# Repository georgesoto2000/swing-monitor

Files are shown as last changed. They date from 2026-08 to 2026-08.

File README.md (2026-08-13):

# Swing Monitor

Arduino sensor project for golf. Mounted IMU sensor on the club shaft allows for live measuring (and transfer of data over IoT/BLE in real time for display) of per-swing metrics, all derived from the shaft-mounted IMU's accelerometer, gyroscope, and fused orientation output.

## Key Metrics

**Speed**
* Peak clubhead speed
* Clubhead speed at impact

**Timing**
* Backswing time (address → top)
* Downswing time (top → impact)
* Tempo ratio (backswing:downswing)
* Total swing time

**Plane**
* Swing plane angle
* Plane angle delta (top of backswing vs. impact)

**Rotational / release**
* Peak angular velocity (wrist/face rotation rate)
* Timing of peak angular velocity relative to impact (early = casting, late = lag/release)

**Impact**
* Peak acceleration spike at impact (magnitude and sharpness)
* Angle of attack at impact (steep vs. shallow) — noisier, since it depends on precise impact detection from the accelerometer alone

## Hardware

* [Ardunio Nano ESP32](https://thepihut.com/products/arduino-nano-esp32-with-headers)
* [Adafruit 9-DOF Orentiation IMU Fusion Breakout - BNO085](https://thepihut.com/products/adafruit-9-dof-orientation-imu-fusion-breakout-bno085-bno080-stemma-qt-qwiic)
* LiPo 3.7v Battery
* 3D printed casing

## Project Plan

1. **Hardware assembly** — wire BNO085 to Nano ESP32 (I2C/Qwiic), confirm power draw against LiPo capacity, mount in 3D printed casing on shaft
2. **Sensor bring-up** — read raw accelerometer/gyroscope and fused orientation (quaternion) output from the BNO085, verify sample rate is sufficient to capture a swing (target 100Hz+) — see [`firmware/sensor_bringup`](firmware/sensor_bringup/sensor_bringup.ino)
3. **Swing event detection** — segment a continuous data stream into address, top of backswing, impact, and finish
4. **Metric calculation** — compute per-swing metrics (speed, timing, plane, rotational/release, impact) from segmented data
5. **Calibration & validation** — sanity-check computed metrics against known reference values (e.g. compare clubhead speed estimates to a radar/launch monitor) and tune impact/event detection thresholds
6. **Data transfer** — stream metrics over BLE from the Nano ESP32
7. **Display** — companion app or device to receive and display metrics in real time
8. **Enclosure refinement** — iterate on 3D printed casing for secure, low-profile shaft mounting

## Python Coding Standards

* All functions and classes should be docstring-ed and type hinted

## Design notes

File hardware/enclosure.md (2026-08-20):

# 3D Print Enclosure

## Requirements

* Enclosure must clip onto the shaft
* Enclosure must contain the PCB and battery
* Enclosure must snap onto the shaft
* USBC is not required to be accessible
* LED is not required to be visible
* PLA filament
* Mounted near grip of golf club
* The Y axis of the PCB should point up the shaft

## Dimensions

* Shaft mounting location diameter: 13mm
* Shaft diameter at the bottom: 9mm
* PCB (and battery): X 45mm, Y 70mm, Z 30mm
* On/off switch hole: 6mm, +X side wall, centered along the case
  length, 5mm below the lid lip's bottom edge

## Open Questions

* Battery retention not decided - fix down (foam tape / printed strap,
  not screws - puncture risk) vs. leave free in the cavity. Currently
  unaddressed in enclosure.scad.

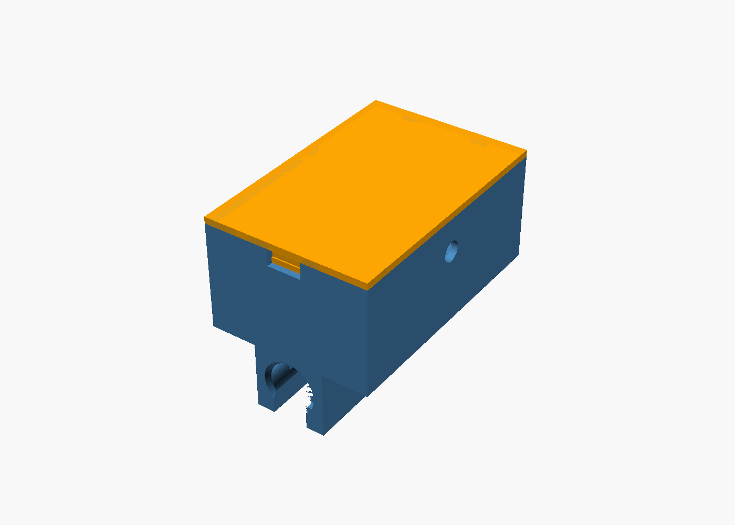
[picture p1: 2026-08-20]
hardware/enclosure_preview.png

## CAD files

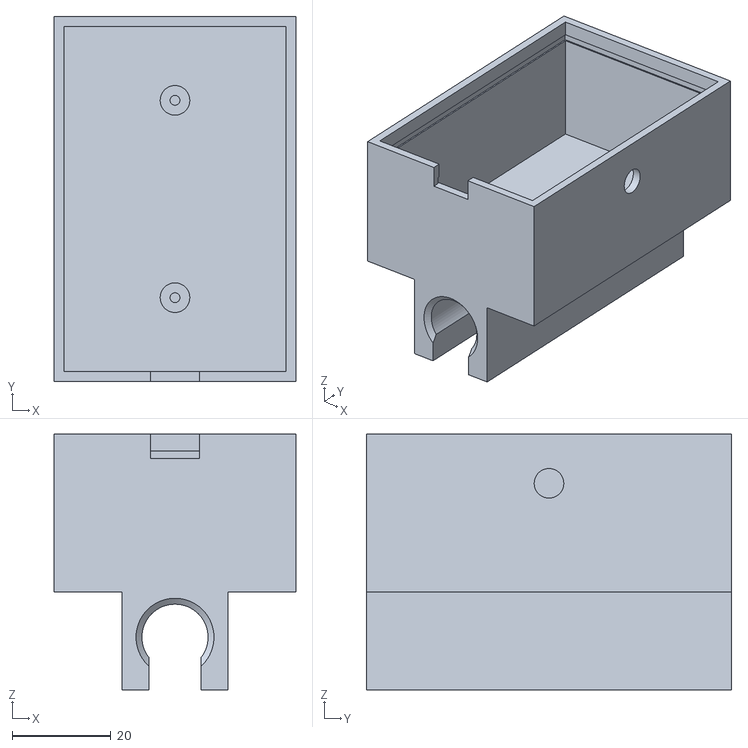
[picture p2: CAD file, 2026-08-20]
hardware/enclosure_base.stl
49.0 x 74.0 x 51.9

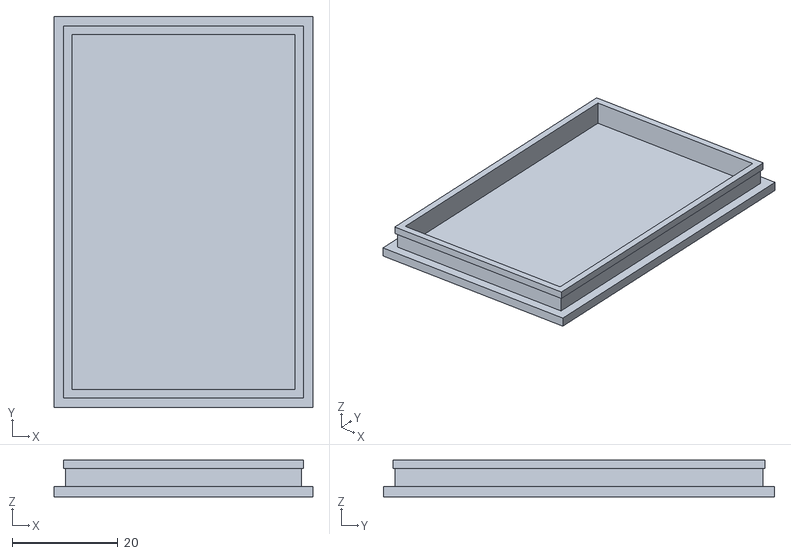
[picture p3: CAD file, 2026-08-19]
hardware/enclosure_lid.stl
49.0 x 74.0 x 7.00

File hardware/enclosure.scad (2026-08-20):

// Swing Monitor - shaft-mount enclosure
// Parametric OpenSCAD model driven by hardware/encloser.md
//
// Design (see chat / README for full rationale):
//  - Two-piece shell: "base" (5 closed sides, open top) + flat "lid"
//    that snaps into the open top via a thin flexible lip with a
//    perimeter bead, which pops into a matching groove in the cavity
//    wall - same thin-wall-interference idea as the shaft clip below,
//    just applied as a rectangular loop instead of a circular one.
//  - A pry notch is cut into one end of the base's rim so there's
//    somewhere to get a fingernail/thin tool under the lid to release
//    the bead and lift it off (it clicks shut positively, so a flush
//    friction-only seam would be very hard to open).
//  - A solid rectangular ring is fused to the underside of the base,
//    bored through with a circular hole for the shaft plus a straight
//    capture slot connecting the bore to the outside (gap facing
//    down). It's installed by clipping it sideways onto the shaft at
//    a point where the shaft is already narrower than the slot (no
//    flexing needed to get it on), then sliding it up the taper until
//    the bore wedges tight at the 13mm mounting point. Because the
//    slot width sits between "narrow enough to clip on" and "too
//    narrow to slip back off at 13mm", it self-retains without ever
//    needing to flex - so the ring can be fully rigid.
//    (v1 used a thin C-clip that snapped on radially by flexing open
//    over the full 13mm - it cracked in testing: PLA has very low
//    elongation at break, and the clip also put a sharp stress-riser
//    right at the weakest print-adhesion seam. v2 tried a fully closed
//    sliding sleeve, but that can't get past a fixed/epoxied clubhead.
//    This version avoids both problems - no flex, and installs without
//    removing the head.)
//  - slot_w = 10.5mm: measured shaft diameter at the clip-on point is
//    ~9mm, so this gives ~1.5mm clearance to clip on without force
//    (also covers FDM holes typically printing a touch undersized),
//    while staying 2.5mm under shaft_d (13mm) so the ring can't slip
//    sideways back off once slid up to the mount point. If the fit
//    feels wrong either way after printing, it's a one-line tweak.
//  - Case Y axis runs parallel to the shaft (per encloser.md: "Y axis
//    of the PCB should point up the shaft").
//
// Assumptions made beyond encloser.md (flagged in chat - revisit after
// a test fit):
//  - encloser.md's PCB+battery box (45 x 70 x 30) is treated as the
//    required INTERNAL cavity, not an outer envelope.
//  - 2mm shell walls, 1.2mm lid-lip walls (thin enough to flex for a
//    PLA snap-fit - the lid still relies on flexing, unlike the sleeve).
//  - Sleeve bore is sized shaft_d + slide_clearance for an easy slide
//    fit; nothing here guarantees it stops/grips exactly at the 13mm
//    point without knowing the real taper profile, so plan on a wrap
//    of grip tape over the sleeve's top edge (traps it from sliding
//    further up) and/or a dab of glue for final retention.
//  - PCB (veroboard, screwed through a flange) sits on two 5mm-tall
//    bosses with blind M2.5 self-tap pilot holes rather than one
//    continuous ledge - same holding strength for a 2-point mount,
//    less material/print time. boss_pos below is a PLACEHOLDER
//    (centered in X, guessed spacing in Y) - it has not been checked
//    against your actual flange hole positions, update it to match
//    before printing for real.
//  - Bead/groove sizes on the lid are a first-pass guess at PLA's
//    flex - print and test; loosen (reduce bead_h) if it's too tight
//    to open, tighten if it doesn't hold.

$fn = 64;

// ---- tunable parameters ----
shaft_d      = 13;    // shaft diameter at the mount point (mm)
box_x        = 45;    // internal cavity width  (X)
box_y        = 70;    // internal cavity length (Y) - parallel to shaft
box_z        = 30;    // internal cavity height (Z)
wall         = 2;     // shell wall thickness (mm)
slide_clear  = 0.4;   // sleeve bore clearance over shaft_d, for sliding on (mm)
sleeve_wall  = 4;     // sleeve wall thickness - rigid, no flex needed (mm)
sleeve_chamfer = 1.2; // lead-in chamfer at the sleeve's ends (mm)
sleeve_overlap = 1.5; // how far the sleeve's top face sits inside the
                       // base's bottom slab (0..wall), for a solid weld
slot_w       = 10.5;  // capture-slot width (mm) - see note above:
                       // shaft-diameter-at-clip-on-point < slot_w < shaft_d
lip_h        = 5;     // lid lip depth (mm)
lip_wall     = 1.2;   // lid lip wall thickness (thin, so it can flex)
lid_clear    = 0.2;   // nominal lid-to-cavity fit clearance per side (mm)
bead_h       = 0.4;   // snap-bead radial projection beyond the lip (mm)
bead_band    = 1.6;   // height of the bead / matching groove band (mm)
groove_clear = 0.15;  // extra clearance in the groove vs the bead (mm)
notch_w      = 10;    // pry-notch width, cut into the rim at y=0 (mm)
notch_d      = 5;     // pry-notch depth, down from the rim (mm)
boss_h       = 5;     // PCB standoff boss height, off the cavity floor (mm)
boss_od      = 6;     // boss outer diameter (mm)
pilot_d      = 2.0;   // pilot hole diameter for a self-tapping M2.5 (mm)
pilot_depth  = 4.5;   // blind pilot hole depth from the boss top (mm)
// PLACEHOLDER positions (x, y) in cavity-local coords: x=0 is the
// cavity centreline, y=0..box_y runs the cavity's length - MUST be
// updated to match your veroboard flange's real hole spacing
boss_pos     = [[0, 15], [0, 55]];

// on/off switch hole - straight through-hole in the +X long wall,
// for a panel-mount toggle/rocker switch (6mm is a common bushing
// size for these - check it matches whatever switch you buy, and
// that its bushing is rated for a ~2mm panel, i.e. the wall thickness)
hole_d       = 6;     // hole diameter (mm)
hole_below_lip = 5;   // "5mm lower than the ledge for the lid" - measured
                       // from the BOTTOM of the lid's lip (z = box_z+wall-lip_h),
                       // not the rim itself, since the rim sits right in the
                       // snap-groove band and a hole there would weaken it

// ---- derived ----
out_x      = box_x + 2*wall;
out_y      = box_y + 2*wall;
sleeve_id  = shaft_d + slide_clear;
sleeve_od  = sleeve_id + 2*sleeve_wall;
lip_ox     = box_x - 2*lid_clear;               // lip outer footprint
lip_oy     = box_y - 2*lid_clear;
lip_ix     = lip_ox - 2*lip_wall;                // lip inner (hollow) footprint
lip_iy     = lip_oy - 2*lip_wall;
groove_x   = lip_ox + 2*bead_h + 2*groove_clear; // groove cut footprint
groove_y   = lip_oy + 2*bead_h + 2*groove_clear;

module shaft_sleeve() {
    // rigid block: circular bore for the shaft, plus a straight
    // capture slot (constant width slot_w) connecting the bore to the
    // outside at the bottom, so the shaft clips in sideways rather
    // than needing to be threaded through an end
    z_center = sleeve_overlap - sleeve_od/2;
    translate([0, 0, z_center]) {
        difference() {
            translate([-sleeve_od/2, 0, -sleeve_od/2])
                cube([sleeve_od, out_y, sleeve_od]);
            rotate([-90, 0, 0])
                cylinder(d = sleeve_id, h = out_y + 2, center = false);
            // lead-in chamfers at both ends so it doesn't catch/scrape
            // as it's slid up the shaft's taper, either way round
            rotate([-90, 0, 0])
                cylinder(d1 = sleeve_id + 2*sleeve_chamfer, d2 = sleeve_id,
                         h = sleeve_chamfer);
            translate([0, out_y - sleeve_chamfer, 0])
                rotate([-90, 0, 0])
                    cylinder(d1 = sleeve_id, d2 = sleeve_id + 2*sleeve_chamfer,
                             h = sleeve_chamfer);
            // capture slot - straight channel from the bore's centre
            // (local z=0) down through the block's bottom face
            translate([-slot_w/2, -1, -sleeve_od/2 - 1])
                cube([slot_w, out_y + 2, sleeve_od/2 + 1]);
        }
    }
}

module groove_2d() {
    difference() {
        square([groove_x, groove_y], center = true);
        square([box_x, box_y], center = true);
    }
}

module pry_notch() {
    // through the y=0 end wall, from the rim down by notch_d
    translate([-notch_w/2, -1, box_z + wall - notch_d])
        cube([notch_w, wall + 2, notch_d + 1]);
}

module side_hole() {
    // on/off switch, panel-mounted through the +X long wall, centered
    // along the case length
    hole_z = (box_z + wall - lip_h) - hole_below_lip;
    translate([out_x/2 - wall - 2, wall + box_y/2, hole_z])
        rotate([0, 90, 0])
            cylinder(d = hole_d, h = wall + 4);
}
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

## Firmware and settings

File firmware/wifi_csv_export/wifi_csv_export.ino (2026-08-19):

// Swing Monitor — Wireless CSV Export (WiFi)
//
// The board hosts its own WiFi hotspot (no router or existing network
// needed — works anywhere, e.g. a driving range) and streams accelerometer,
// gyroscope, and rotation vector (quaternion) readings as CSV rows over TCP
// to whichever laptop joins that hotspot.
//
// Setup:
// 1. Upload and power the board (USB or battery). It'll print its hotspot
//    SSID and IP address (normally 192.168.4.1) to Serial.
// 2. On your laptop, join the WiFi network below (you'll lose general
//    internet access while connected — expected, the board isn't routing
//    to the internet).
// 3. Start capturing to a file:
//        nc 192.168.4.1 5005 > swing_data.csv
// 4. When done, Ctrl+C the `nc` command to close the file.
//
// CSV columns: millis,type,x,y,z,w  (w only populated for QUAT rows)

#include <Wire.h>
#include <WiFi.h>
#include <Adafruit_BNO08x.h>

const char* AP_SSID = "swing-monitor";
const char* AP_PASSWORD = "swingmonitor123";  // WPA2 requires 8+ characters
const uint16_t SERVER_PORT = 5005;

#define BNO08X_RESET -1

Adafruit_BNO08x bno08x(BNO08X_RESET);
sh2_SensorValue_t sensorValue;
WiFiServer server(SERVER_PORT);
WiFiClient client;

// 200Hz — comfortably above the 100Hz+ target.
const uint32_t REPORT_INTERVAL_US = 5000;

void setReports() {
  bno08x.enableReport(SH2_ACCELEROMETER, REPORT_INTERVAL_US);
  bno08x.enableReport(SH2_GYROSCOPE_CALIBRATED, REPORT_INTERVAL_US);
  bno08x.enableReport(SH2_ROTATION_VECTOR, REPORT_INTERVAL_US);
}

void startAccessPoint() {
  WiFi.softAP(AP_SSID, AP_PASSWORD);
  Serial.print("Hotspot \"");
  Serial.print(AP_SSID);
  Serial.print("\" up, IP: ");
  Serial.println(WiFi.softAPIP());
  server.begin();
}

void setup() {
  Serial.begin(115200);

  startAccessPoint();

  if (!bno08x.begin_I2C()) {
    Serial.println("Failed to find BNO085 - check wiring");
    while (1) {
      delay(10);
    }
  }

  // Bump from the 100kHz default to 400kHz (I2C fast mode) — set after
  // begin_I2C() so the library's own Wire.begin() doesn't reset it back.
  Wire.setClock(400000);

  setReports();

  Serial.println("Waiting for laptop to connect...");
}

void sendRow(uint32_t t, const char* type, float x, float y, float z, float w, bool hasW) {
  // Build the whole row and send it as a single write — sending each field
  // as a separate client.print() call was six TCP writes per sample, which
  // over WiFi was slow enough to throttle the achievable sample rate well
  // below the sensor's actual output rate.
  char buf[96];
  int len;
  if (hasW) {
    len = snprintf(buf, sizeof(buf), "%lu,%s,%.4f,%.4f,%.4f,%.4f\n", t, type, x, y, z, w);
  } else {
    len = snprintf(buf, sizeof(buf), "%lu,%s,%.4f,%.4f,%.4f,\n", t, type, x, y, z);
  }
  client.write((const uint8_t*)buf, len);
}

void loop() {
  if (bno08x.wasReset()) {
    setReports();
  }

  if (!client.connected()) {
    client = server.available();
    if (client) {
      client.setNoDelay(true);  // don't let TCP delay small writes waiting to batch
      Serial.println("Laptop connected - streaming CSV");
      client.println("millis,type,x,y,z,w");
    }
    return;
  }

  if (!bno08x.getSensorEvent(&sensorValue)) {
    return;
  }

  uint32_t t = millis();

  switch (sensorValue.sensorId) {
    case SH2_ACCELEROMETER:
      sendRow(t, "ACCEL", sensorValue.un.accelerometer.x,
              sensorValue.un.accelerometer.y, sensorValue.un.accelerometer.z,
              0, false);
      break;

    case SH2_GYROSCOPE_CALIBRATED:
      sendRow(t, "GYRO", sensorValue.un.gyroscope.x,
              sensorValue.un.gyroscope.y, sensorValue.un.gyroscope.z, 0,
              false);
      break;

    case SH2_ROTATION_VECTOR:
      sendRow(t, "QUAT", sensorValue.un.rotationVector.i,
              sensorValue.un.rotationVector.j, sensorValue.un.rotationVector.k,
              sensorValue.un.rotationVector.real, true);
      break;
  }
}

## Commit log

2026-08-13 chore: add missing files from commit pycache and reamde
    [wifi_csv_export.ino]
2026-08-13 feat(app): add first-pass swing metrics and stacked Raw/Swing tabs
    Splits the live view into a Raw tab (existing per-channel time-series
    charts, now stacked full-width with a millisecond-precision timestamp
    axis) and a new Swing tab showing peak angular velocity, an estimated
    clubhead speed (scaled by a per-club hands-to-clubface lever arm,
    selectable PW-5i), and the peak acceleration spike with its sharpness.
2026-08-13 feat(app): add per-metric trend charts to the Swing tab, stack layout
    Adds a small time-series chart under each Swing tab metric (angular
    velocity, estimated clubhead speed, accel spike), reusing the same
    timestamp-formatted axis as the Raw tab. Stacks the three metrics
    vertically instead of side-by-side columns, matching the Raw tab's
    layout, and makes swing_metrics.magnitude() public so the app can
    reuse it for chart data.
2026-08-13 feat(app): add selectable rolling window for the live graphs
    Adds an Auto/5s/10s/15s/20s dropdown controlling how much history the
    Raw and Swing tab graphs (and Swing tab peak calculations) show, on
    top of the buffer capacity bump needed to actually retain 20s of
    history at the sensor's ~200Hz report rate.
2026-08-13 feat(app): log live sessions to CSV, add pause, refresh Swing tab UI
    - SwingStream now writes every transmitted ACCEL/GYRO/QUAT row to a
    timestamped CSV under data/sessions/ from the background read
    thread, independent of UI redraws
    - Add a freeze/pause toggle that stops charts updating while still
    recording in the background
    - Make Swing the default/leftmost tab, drop stale captions/notes,
    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
2026-08-13 chore(firmware): remove redundant sensor_bringup sketch
    Superseded by firmware/wifi_csv_export, which the app now connects
    to directly.
2026-08-13 feat(app): tighten Swing tab controls, replace freeze toggle with pause button
    - Narrow the Rolling window / Club / Pause controls to fit their
    content instead of spanning full width, and group Club with
    Rolling window
    - Swap the freeze toggle for a Pause/Resume button
    - Reword status and session captions, drop the per-metric captions
    between each Peak value and its trend chart, remove now-unused
    _fmt_time helper
2026-08-19 fix(firmware): remove block if no serial
    [wifi_csv_export.ino]
2026-08-19 feat(hardware): add 3d enclosure design
    [enclosure.scad, enclosure_base.stl, enclosure_lid.stl]
2026-08-20 feat(hardware): create 2nd version of enclosure make the c clamp a fixed component with supports that doesn't flex
    [enclosure.scad, enclosure_base.stl]
